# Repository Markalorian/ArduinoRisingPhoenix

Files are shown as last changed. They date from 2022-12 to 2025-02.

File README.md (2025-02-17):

# Arduino [Rising Phoenix](https://starwars.fandom.com/wiki/Rising_Phoenix) Electronics
Open-source electronics project for the Rising Phoenix jetpack worn by Din Djarin in 'The Mandalorian'.

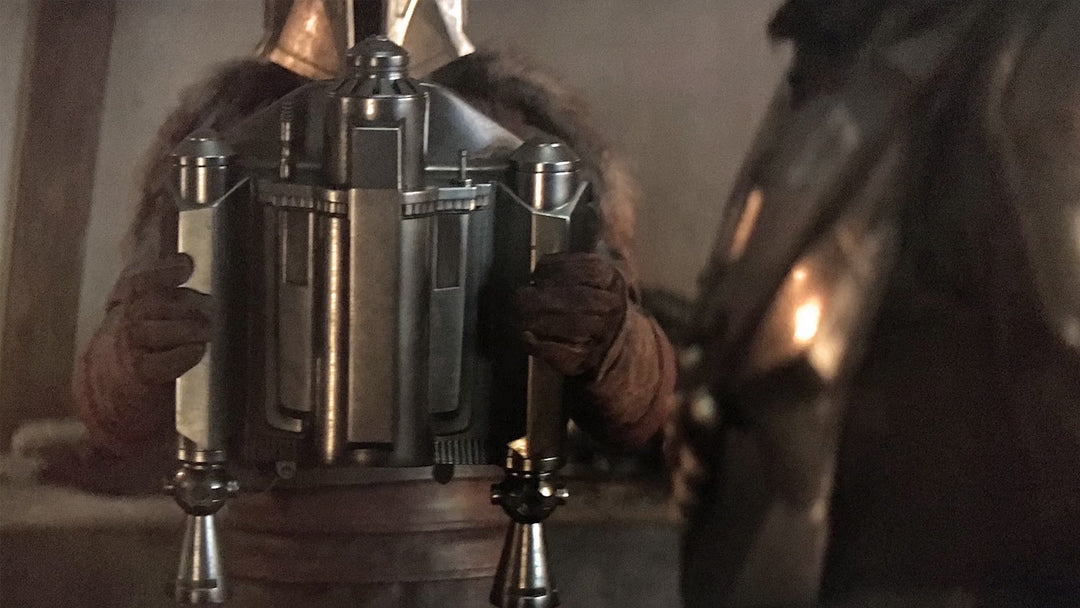
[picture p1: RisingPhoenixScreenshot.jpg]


Includes LEDs with flame effect, sound effects, and smoke that is all controlled by a wireless remote.

[Buy a Rising Phoenix PCB here](https://markalorian.gumroad.com/l/risingphoenixpcb)
Currently out of stock. The .ino file to have your own made is available above however.

Video Demo - https://www.youtube.com/shorts/M8bbbQtCOJw

Follow me on Instagram - https://www.instagram.com/the_markalorian/

## Parts list
In addition to the 3d printed parts available in the files section, you will need the following:
1) [Arduino Nano](https://smile.amazon.com/gp/product/B0713XK923/) - controller for this project.
2) [Rising Phoenix board](https://markalorian.gumroad.com/l/risingphoenixpcb) (or blank [prototyping PCBs](https://smile.amazon.com/gp/product/B072Z7Y19F/) and [connectors](https://smile.amazon.com/gp/product/B088LSS14J/)).
3) [DFPlayer Mini](https://www.dfrobot.com/product-1121.html) - get an authentic one made by DFRobot. The knock-offs didn't work in my experience.
4) Micro SD card - any size should do.
5) [1k ohm resistor](https://smile.amazon.com/gp/product/B07QG1V4YL/) - for the DFPlayer's RX pin. (This is included with the Rising Phoenix board.)
6) [12v mini amplifier](https://smile.amazon.com/gp/product/B08GYQTTXF/) - to increase the output of the DFPlayer Mini.
7) (2) [25mm exciters](https://smile.amazon.com/gp/product/B00M292316/) - these stick to the inside of the pack to create the sound.
8) (2) [16 bit Neopixel LED rings](https://smile.amazon.com/Adafruit-NeoPixel-Ring-Integrated-Drivers/dp/B00KBXT9I0/) - to place inside the thrusters for the flame effect. Other brands with WS2812B or SK6812-based LEDs should also work, but you may need to change one line in the Arduino .ino file
9) (4) [5v relay modules](https://smile.amazon.com/gp/product/B09G6H7JDT/) - to activate the various components.
10) (2) [5v 5015 blower fans](https://smile.amazon.com/gp/product/B07V2KVQB7/) - used to increase airflow of smoke.
11) (2) [12v mini air pumps](https://smile.amazon.com/gp/product/B0786BQYKM/) - used to push air through the vaporizers.
12) (2) ecig vaporizers/atomizers - the [Kanger T2](https://www.google.com/search?q=kanger+t2+clearomizer) design seems works best and what this project was designed for but they are getting hard to find.
  Optional (2) [510 threaded connectors](https://www.aliexpress.us/item/3256804393659205.html) - Makes connecting the negative wire to the atomizor much easier
13) (2) [18650 batteries](https://www.18650batterystore.com/products/molicel-p26a) - need a high current output. These power the vaporizers.
14) [Talentcell 3000 mAh rechargable battery pack](https://smile.amazon.com/gp/product/B01M7Z9Z1N/) - provides both 5v and 12v power to everything except the vaporizers. Will not automatically power off like most USB battery packs.
15) [Wiress RF remote](https://www.amazon.com/gp/product/B077ZQMQDZ) - to activate the jetpack. 
16) [Silicone Tubing 4mm ID X 6mm OD](https://smile.amazon.com/gp/product/B07V5MX1Q4/)
17) [Silicone Tubing 8mm ID x 11mm OD](https://smile.amazon.com/gp/product/B07V5PKYMK/)
18) [24-22 AWG hookup wire](https://smile.amazon.com/gp/product/B073QHPGMC/)
19) [Ferrule Connectors](https://www.amazon.com/Ferrule-Crimping-Tools-Wire-Pliers/dp/B07WRQN45C/) - Optional
20) [Wago lever nuts](https://smile.amazon.com/gp/product/B07W4RQ6R6/) - Optional - for some of the 12v wire connections

## Wiring Diagram
Using custom Rising Phoenix board
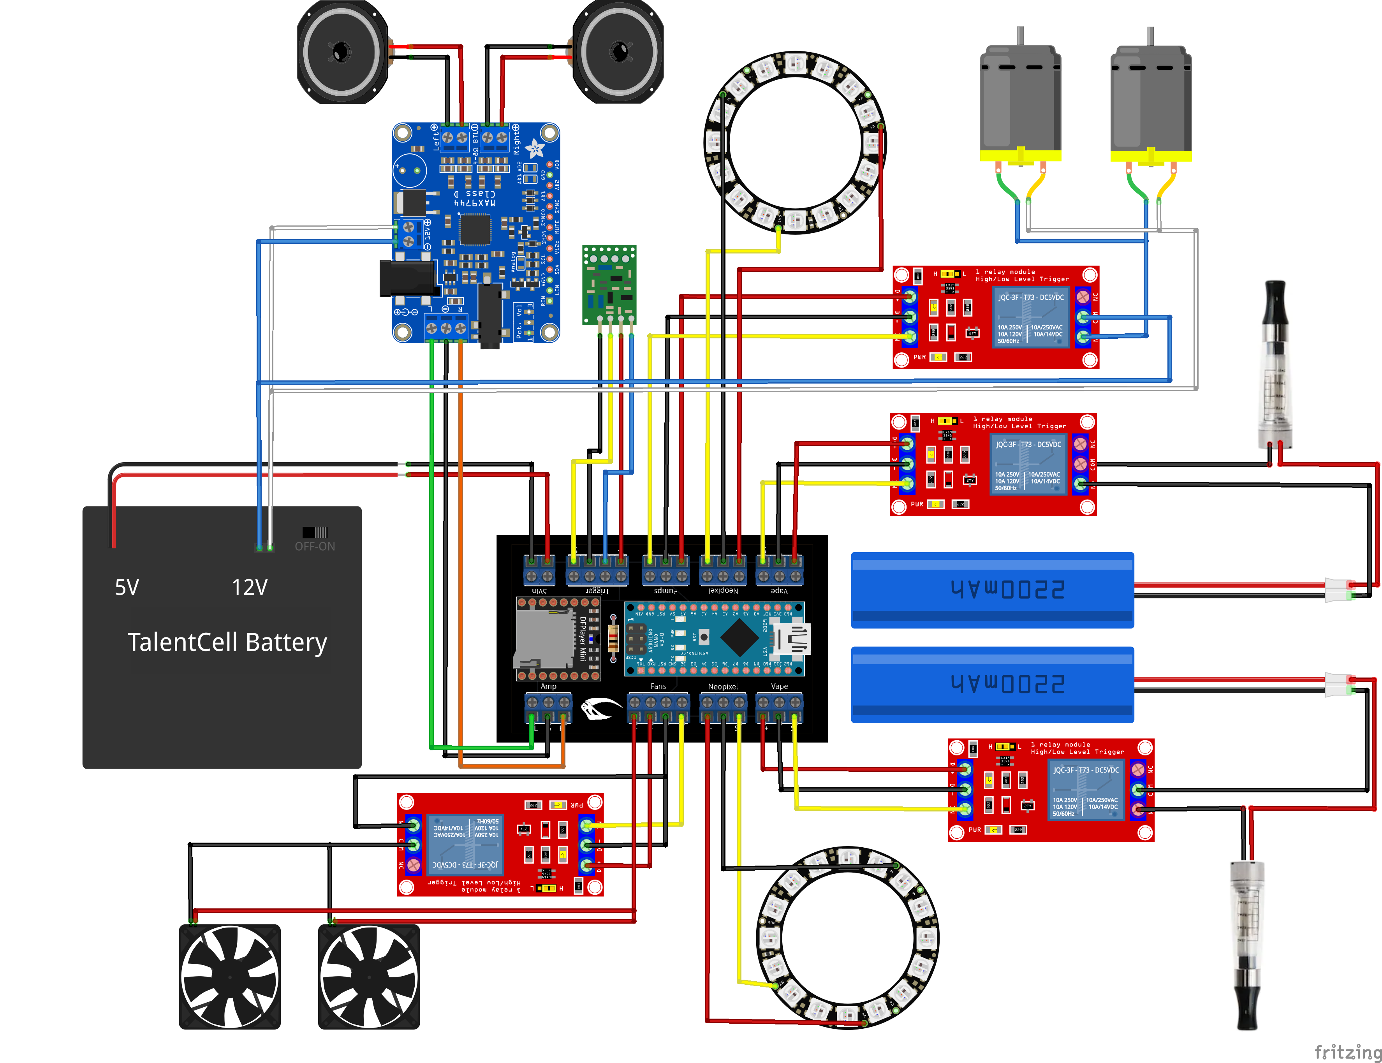
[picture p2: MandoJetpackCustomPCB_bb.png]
Custom PCB Diagram


Using prototype board
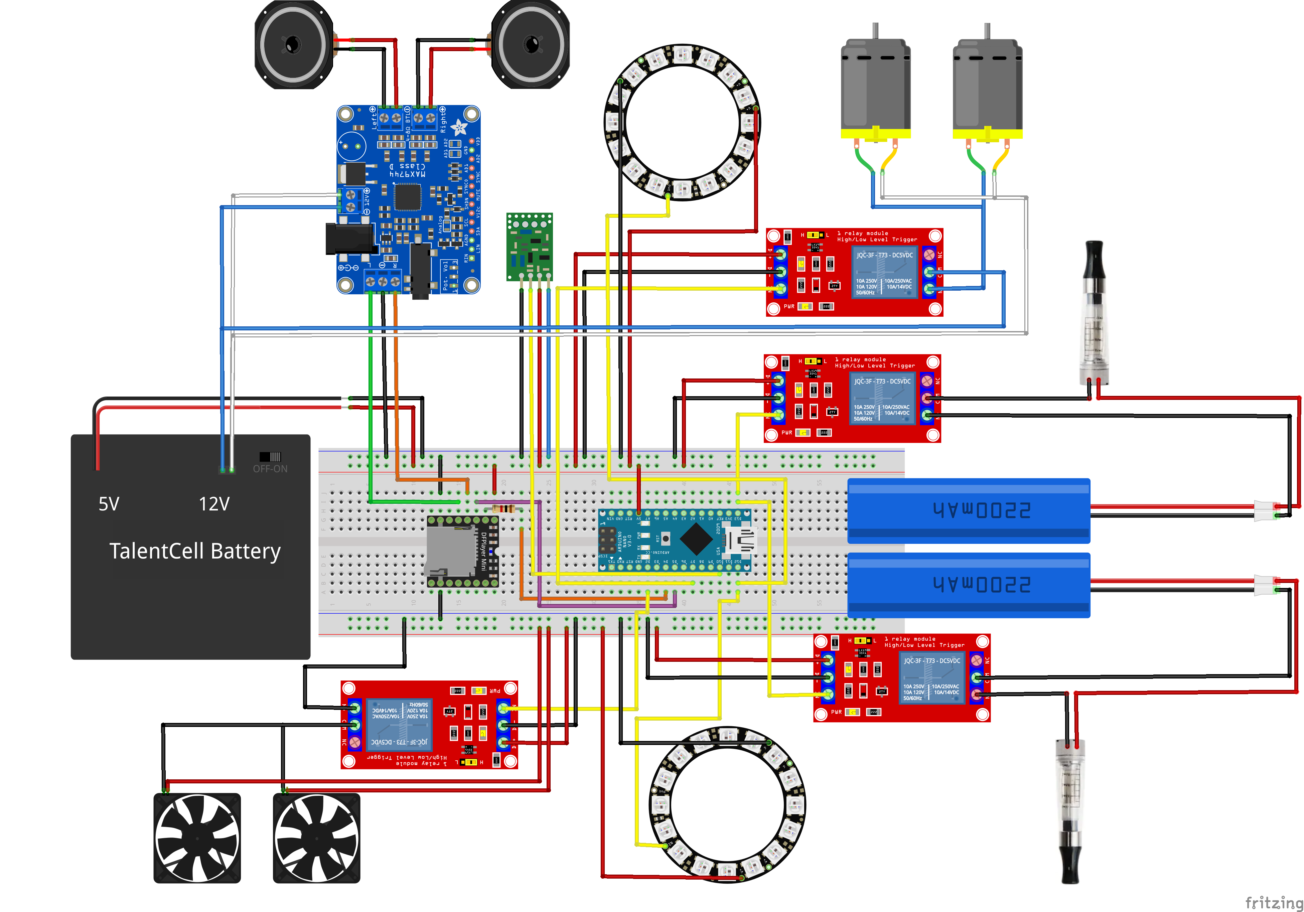
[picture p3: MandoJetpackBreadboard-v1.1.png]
Breadboard Diagram


## Instructions

Detailed instructions coming soon

Custom PCB
Full Interior
Left Side 1
Left Side 2
Right Side 1
Right Side 2

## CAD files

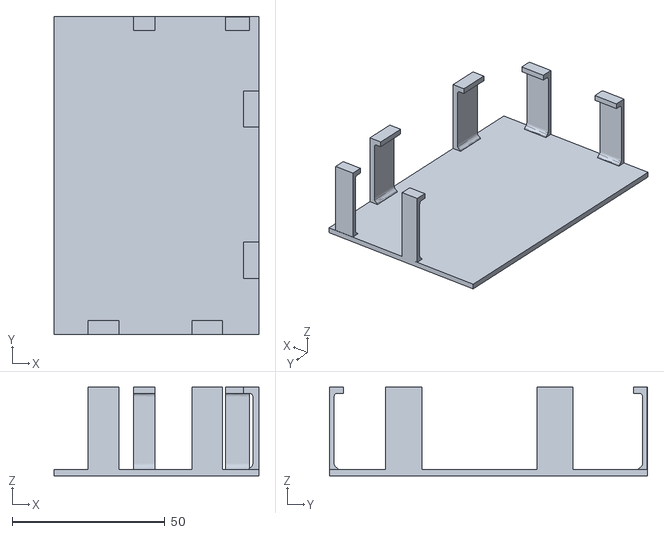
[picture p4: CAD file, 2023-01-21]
3D Print Files/Talentcell 3000 Battery holder V2.stl
67.0 x 104.0 x 29.0

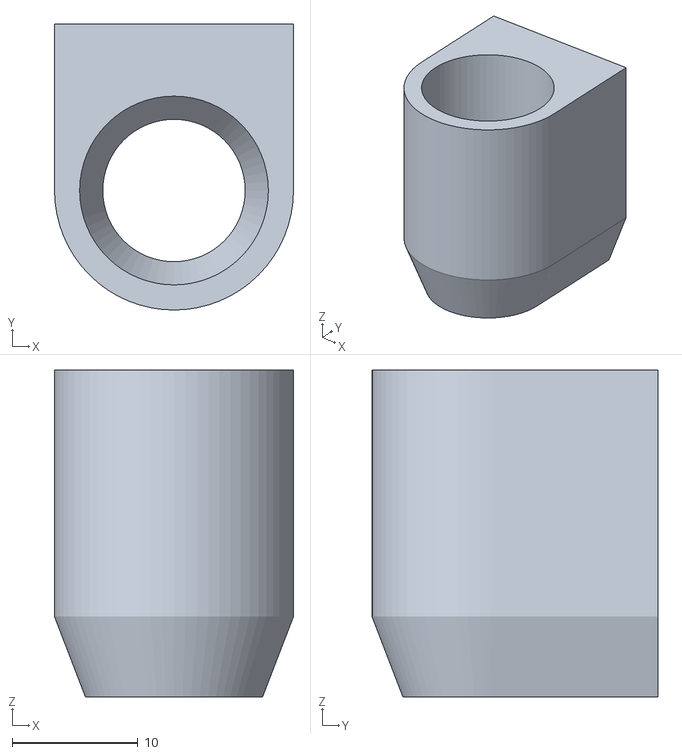
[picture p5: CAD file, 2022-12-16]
3D Print Files/Jetpack Vape Holder 15mm v3.stl
19.0 x 22.7 x 26.0

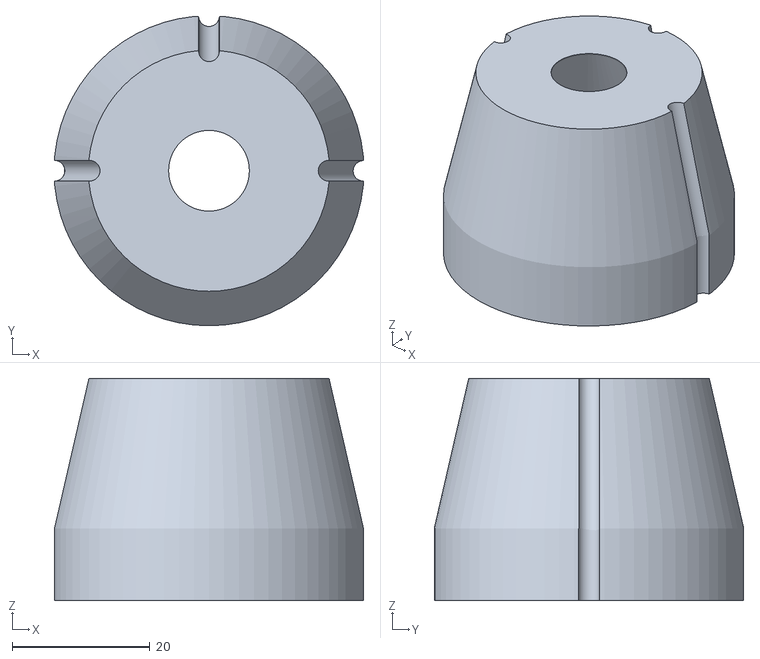
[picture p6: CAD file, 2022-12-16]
3D Print Files/Jetpack Neopixel Holder 105_.stl
44.9 x 44.9 x 32.3

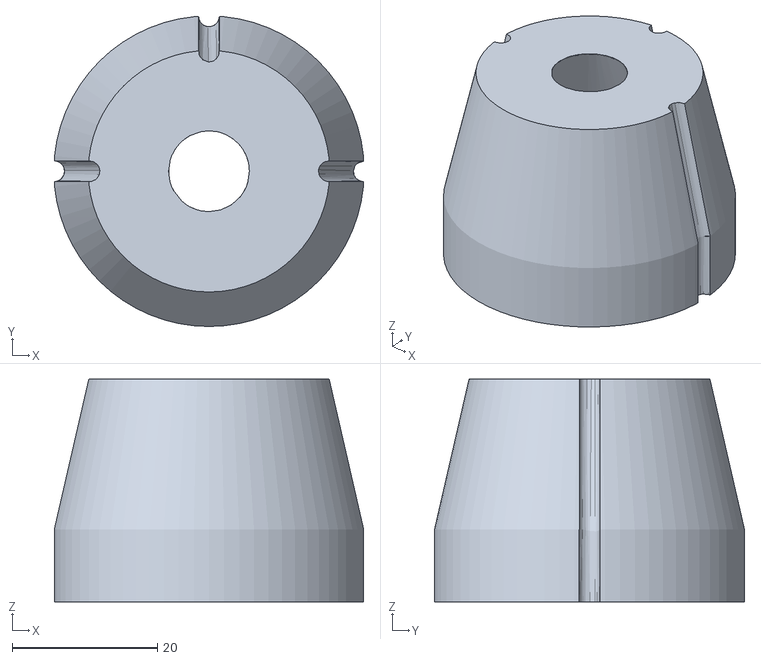
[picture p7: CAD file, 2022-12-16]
3D Print Files/Jetpack Neopixel Holder 100_.stl
42.6 x 42.7 x 30.7

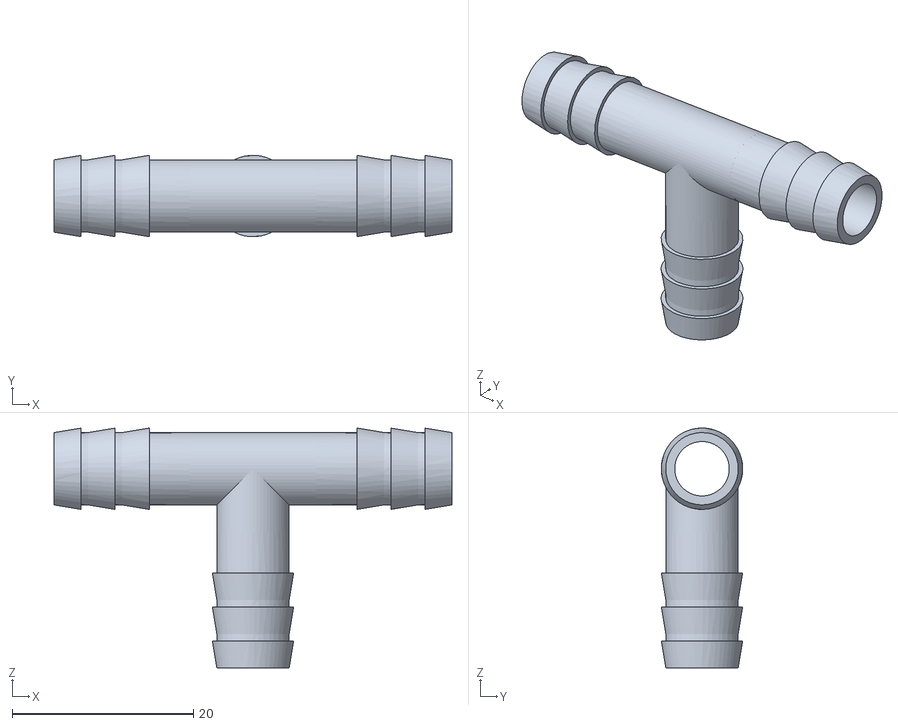
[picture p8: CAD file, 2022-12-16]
3D Print Files/8mm ID hose T Connector.stl
43.9 x 8.99 x 26.5

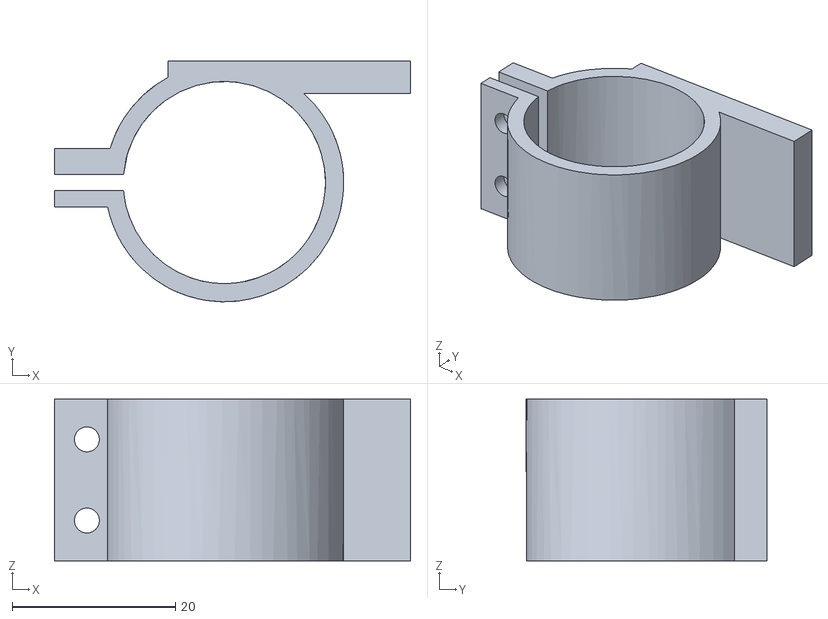
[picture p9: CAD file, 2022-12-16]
3D Print Files/Air pump mount v2.stl
43.6 x 29.4 x 19.8

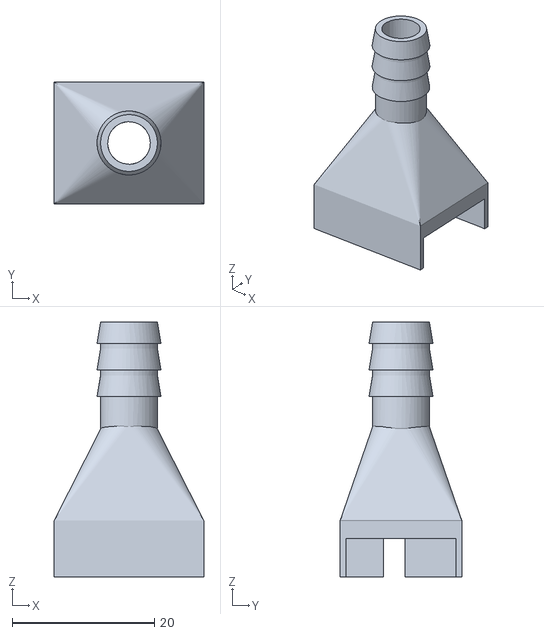
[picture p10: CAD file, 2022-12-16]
3D Print Files/5015 Blower Fan to 8mm ID tube v4.stl
21.0 x 17.1 x 35.8

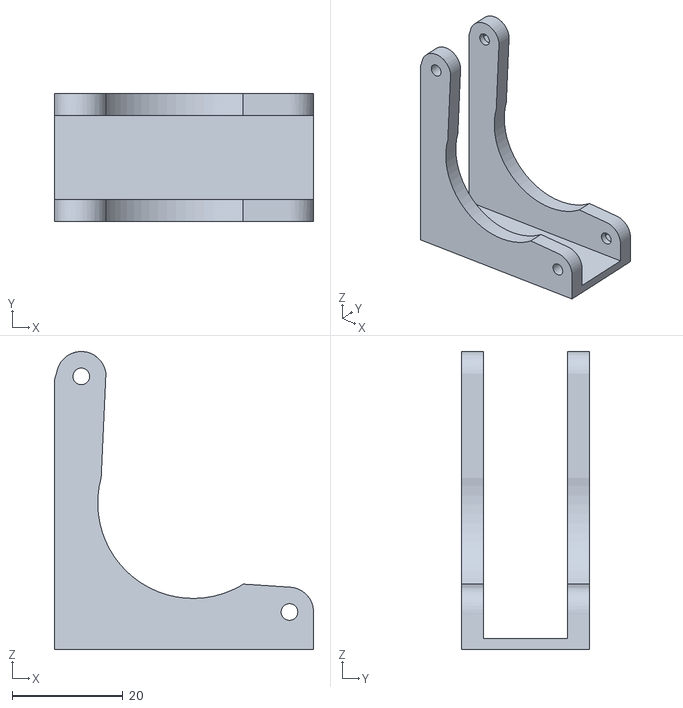
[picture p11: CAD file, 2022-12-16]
3D Print Files/5015 Fan Bracket v3.stl
46.9 x 23.2 x 53.9

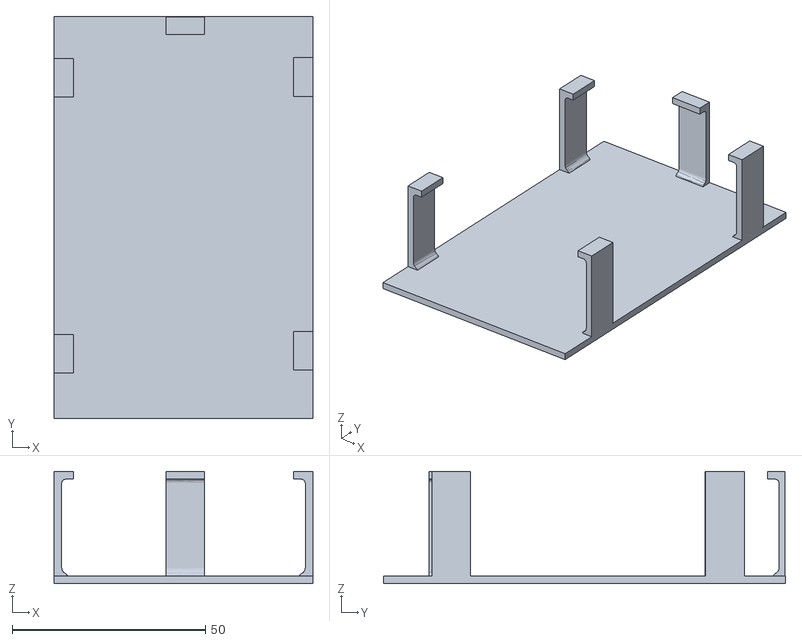
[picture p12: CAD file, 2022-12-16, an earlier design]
3D Print Files/Talentcell 3000 Battery holder.stl
67.0 x 104.0 x 29.0

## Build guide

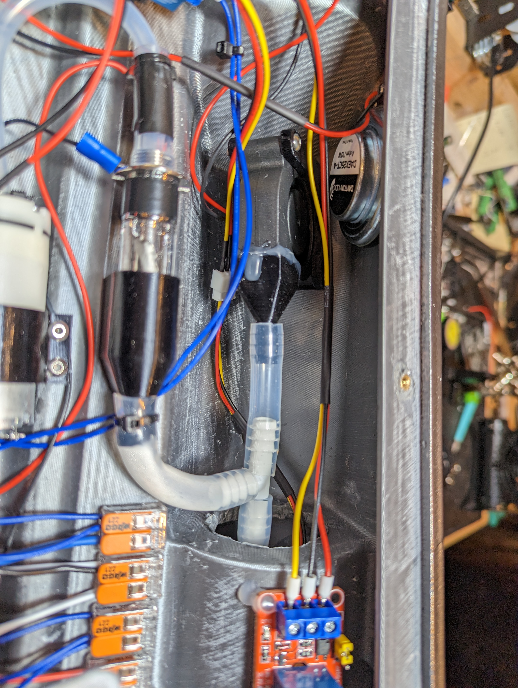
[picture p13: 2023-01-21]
Build Pictures/Right Side 2.jpg

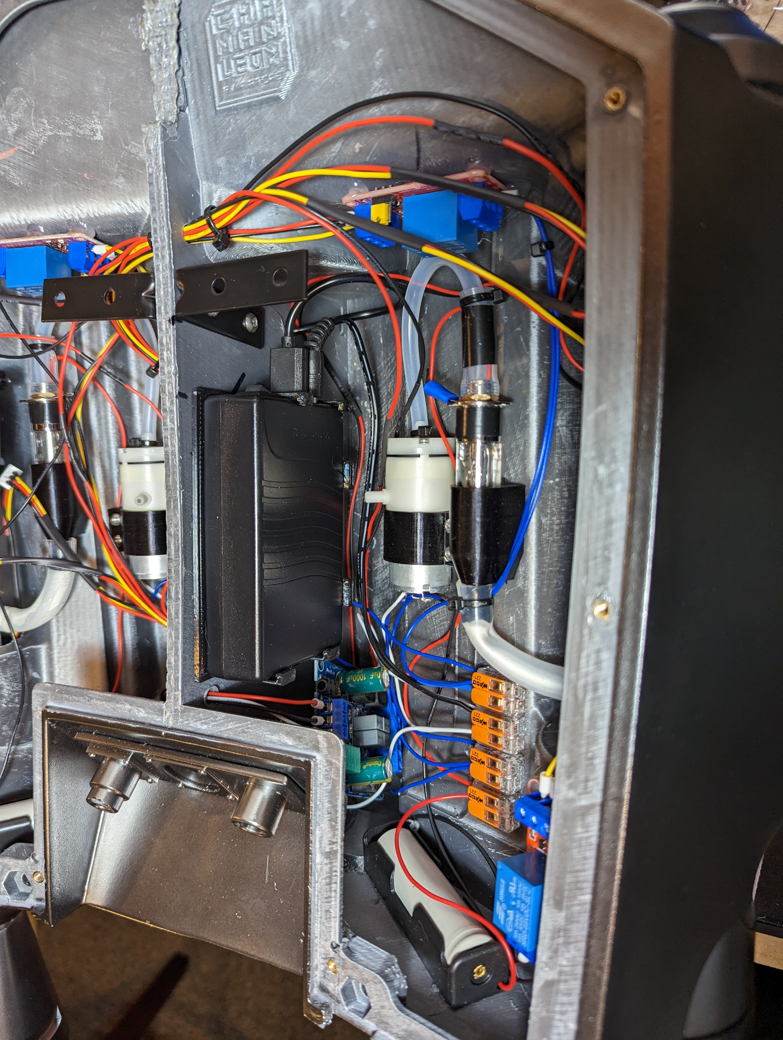
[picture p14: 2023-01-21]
Build Pictures/Right Side 1.jpg

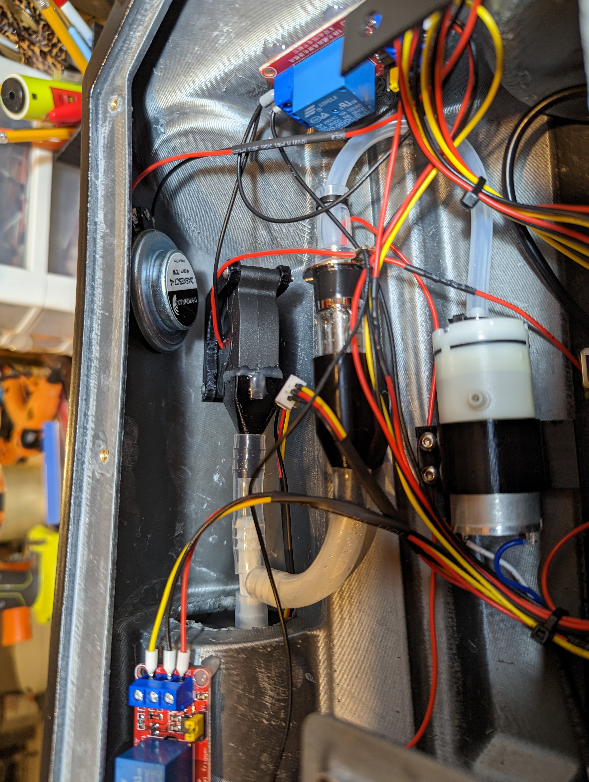
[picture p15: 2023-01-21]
Build Pictures/Left Side 2.jpg

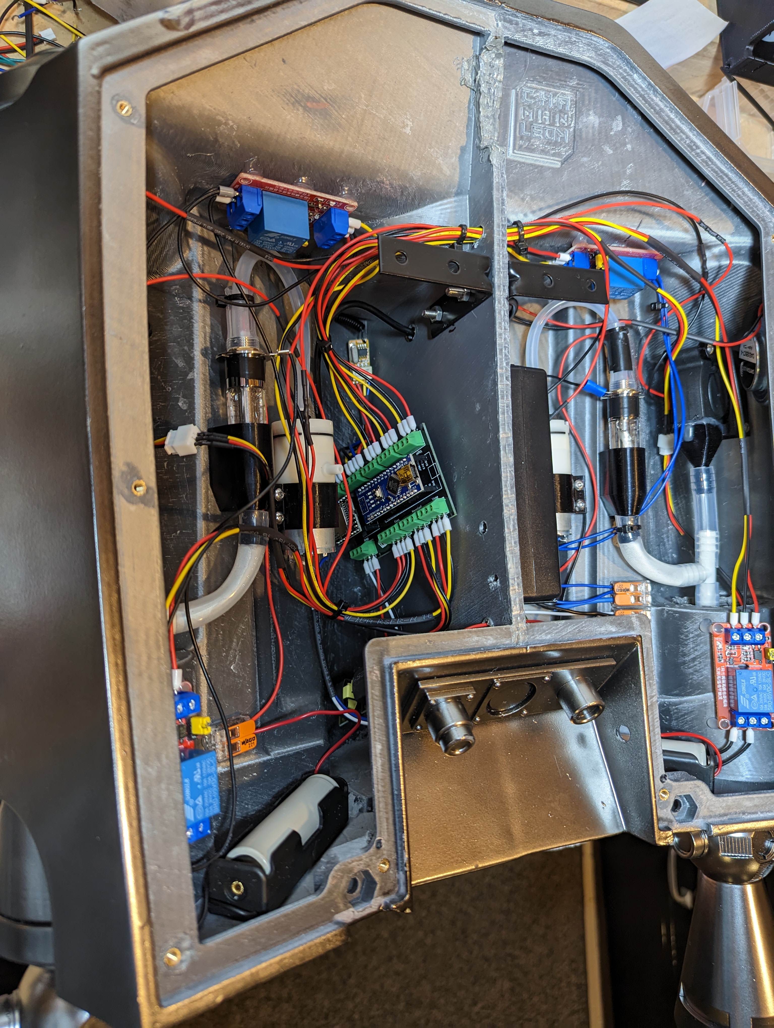
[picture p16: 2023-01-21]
Build Pictures/Left Side 1.jpg

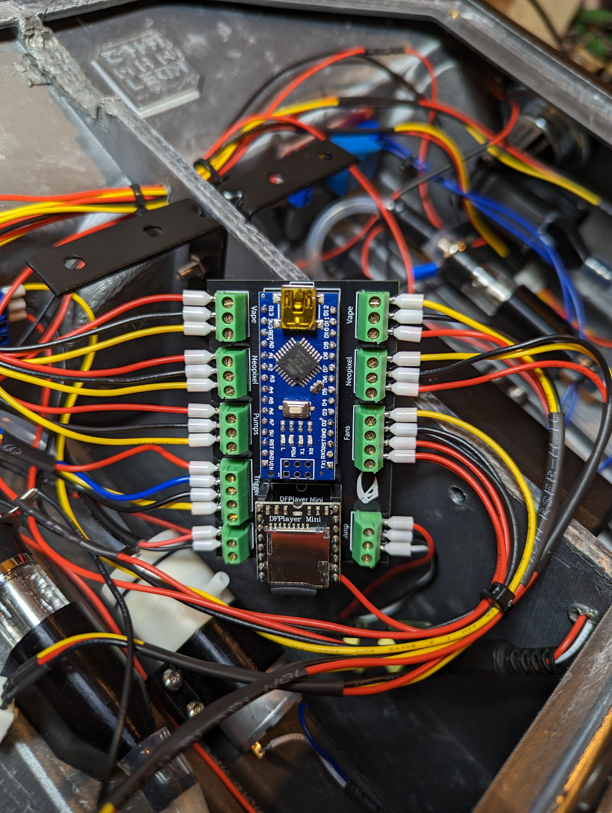
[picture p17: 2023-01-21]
Build Pictures/PCB Installed.jpg

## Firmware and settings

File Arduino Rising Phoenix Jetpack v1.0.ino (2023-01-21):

//Arduino Rising Phoenix Jetpack Version 1.0
//Created by Mark Konior
//Neopixel Fire Simulation code written by Robo Ulbricht - https://github.com/RoboUlbricht/arduinoslovakia/tree/master/neopixel/neopixel_fire01
//
//This code is covered by a Creative Commons Attribution-NonCommercial-ShareAlike 4.0 International Public License - https://github.com/konior21/ArduinoRisingPhoenix/blob/main/LICENSE
//
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
#include <Adafruit_NeoPixel.h>
#include <SoftwareSerial.h>
#include <DFPlayerMini_Fast.h>
SoftwareSerial mySerial(4, 3); // RX, TX Pins on Nano to DFPlayer Mini
DFPlayerMini_Fast myMP3;

#define PIN 12 // Neopixel Pin
// led count
#define CNT 16

// Parameter 1 = number of pixels in strip
// Parameter 2 = pin number (most are valid)
// Parameter 3 = pixel type flags, add together as needed:
//   NEO_RGB     Pixels are wired for RGB bitstream
//   NEO_GRB     Pixels are wired for GRB bitstream
//   NEO_KHZ400  400 KHz bitstream (e.g. FLORA pixels)
//   NEO_KHZ800  800 KHz bitstream (e.g. High Density LED strip)
Adafruit_NeoPixel strip = Adafruit_NeoPixel(CNT, PIN, NEO_GRB + NEO_KHZ800);

///
/// Fire simulator
///

uint32_t fire_color   = strip.Color ( 255,  100,  00);
uint32_t off_color    = strip.Color (  0,  0,  0);

class NeoFire
{
  Adafruit_NeoPixel &strip;
 public:

  NeoFire(Adafruit_NeoPixel&);
  void Draw();
  void Clear();
  void AddColor(uint8_t position, uint32_t color);
  void SubstractColor(uint8_t position, uint32_t color);
  uint32_t Blend(uint32_t color1, uint32_t color2);
  uint32_t Substract(uint32_t color1, uint32_t color2);
};

///
/// Constructor
///
NeoFire::NeoFire(Adafruit_NeoPixel& n_strip)
: strip (n_strip)
{
}

///
/// Set all colors
///
void NeoFire::Draw()
{
Clear();

for(int i=0;i<CNT;i++)
  {
  AddColor(i, fire_color);
  int r = random(50,150);
  uint32_t diff_color = strip.Color ( r, r/2, r/2);
  SubstractColor(i, diff_color);
  }
  
strip.show();
}

///
/// Set color of LED
///
void NeoFire::AddColor(uint8_t position, uint32_t color)
{
uint32_t blended_color = Blend(strip.getPixelColor(position), color);
strip.setPixelColor(position, blended_color);
}

///
/// Set color of LED
///
void NeoFire::SubstractColor(uint8_t position, uint32_t color)
{
uint32_t blended_color = Substract(strip.getPixelColor(position), color);
strip.setPixelColor(position, blended_color);
}

///
/// Color blending
///
uint32_t NeoFire::Blend(uint32_t color1, uint32_t color2)
{
uint8_t r1,g1,b1;
uint8_t r2,g2,b2;
uint8_t r3,g3,b3;

r1 = (uint8_t)(color1 >> 16),
g1 = (uint8_t)(color1 >>  8),
b1 = (uint8_t)(color1 >>  0);

r2 = (uint8_t)(color2 >> 16),
g2 = (uint8_t)(color2 >>  8),
b2 = (uint8_t)(color2 >>  0);

return strip.Color(constrain(r1+r2, 0, 255), constrain(g1+g2, 0, 255), constrain(b1+b2, 0, 255));
}

///
/// Color blending
///
uint32_t NeoFire::Substract(uint32_t color1, uint32_t color2)
{
uint8_t r1,g1,b1;
uint8_t r2,g2,b2;
uint8_t r3,g3,b3;
int16_t r,g,b;

r1 = (uint8_t)(color1 >> 16),
g1 = (uint8_t)(color1 >>  8),
b1 = (uint8_t)(color1 >>  0);

r2 = (uint8_t)(color2 >> 16),
g2 = (uint8_t)(color2 >>  8),
b2 = (uint8_t)(color2 >>  0);

r=(int16_t)r1-(int16_t)r2;
g=(int16_t)g1-(int16_t)g2;
b=(int16_t)b1-(int16_t)b2;
if(r<0) r=0;
if(g<0) g=0;
if(b<0) b=0;

return strip.Color(r, g, b);
}

///
/// Every LED to black
///
void NeoFire::Clear()
{
for(uint16_t i=0; i<strip.numPixels (); i++)
  strip.setPixelColor(i, off_color);
}

NeoFire fire(strip);

//[GLOBAL_VARIABLES]
int btnPin = 10;

boolean isBtn(){
   int a = digitalRead(btnPin);
     if(!a){
       return true;
     }
     else{
       return false;
     }
}

int cnt1 = 0;
int cnt2 = 0;

int pump = 7;
int fan = 2;
int vape = 13;

boolean btnPressed = false;
int cnt = 0;
int delayApplied = true;
int delayTime = 1400; //Delay before Neopixels activate. You can adjust if needed (in ms).

void DelayTimer(long int DelayValue){
  long int DelayTime = millis();
  do {

if(!delayApplied){
       delay(delayTime);
       delayApplied = true;
      }
    

   fire.Draw();
   delay(random(25,125)); //Rate of color change for fire effect
     if(!isBtn()){
       break;
    }
  }while (millis()-DelayTime < DelayValue);
}


void setup() {
  pinMode(btnPin, INPUT_PULLUP);
   pinMode(pump, OUTPUT);
    pinMode(fan, OUTPUT);
     pinMode(vape, OUTPUT);
  strip.begin();
strip.show(); 
 mySerial.begin(9600);
  myMP3.begin(mySerial, true);
   myMP3.volume(30);
}



void loop() {

  if(isBtn()){
    btnPressed = true;
    activatePumps();
    activateFans();
    activateVape();
     
     myMP3.play(1); //0001.mp3, the starting sound
     DelayTimer(40000);
   
  }
  else{
     if(btnPressed){
      delayApplied = false;
      for(uint16_t i=0; i<strip.numPixels (); i++){
        strip.setPixelColor(i, off_color);
      }
      strip.show();
       deactivateVape();
        deactivatePumps();
        deactivateFans();
        myMP3.play(2); //0002.mp3, the ending sound
        btnPressed = false;
         
     }
  }
}

void activateVape(){
   digitalWrite(vape, HIGH);
   
}

void deactivateVape(){
   digitalWrite(vape, LOW);
   
}

void activatePumps(){
   digitalWrite(pump, HIGH);
   
}

void deactivatePumps(){
   digitalWrite(pump, LOW);
   
}

void activateFans(){
   digitalWrite(fan, HIGH);

}

void deactivateFans(){
   digitalWrite(fan, LOW);

}

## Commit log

2022-12-16 Create Print Instructions
2025-02-17 Update README.md
    -Fixed link for Wireless RF Remote
